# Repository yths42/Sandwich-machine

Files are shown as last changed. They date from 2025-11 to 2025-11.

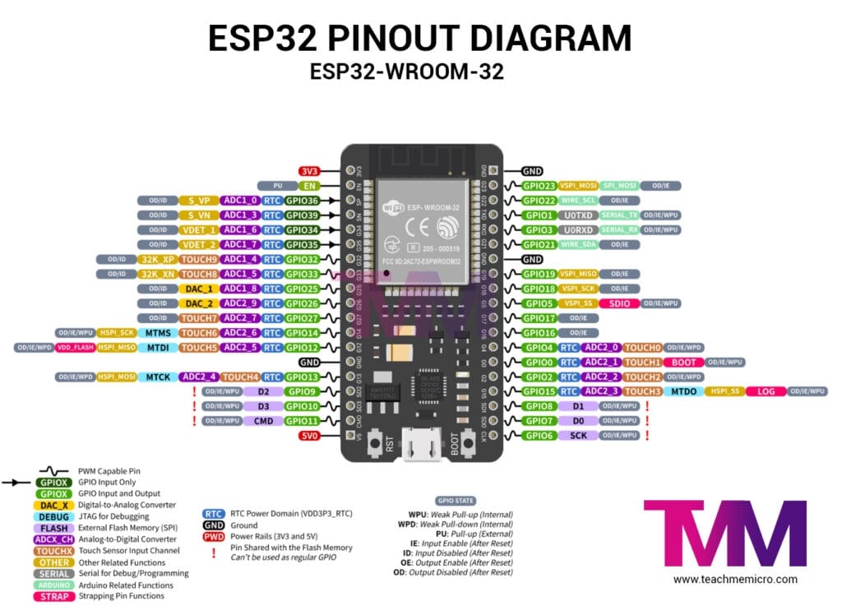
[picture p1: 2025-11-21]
ESP32 Pinout Diagram.jpg

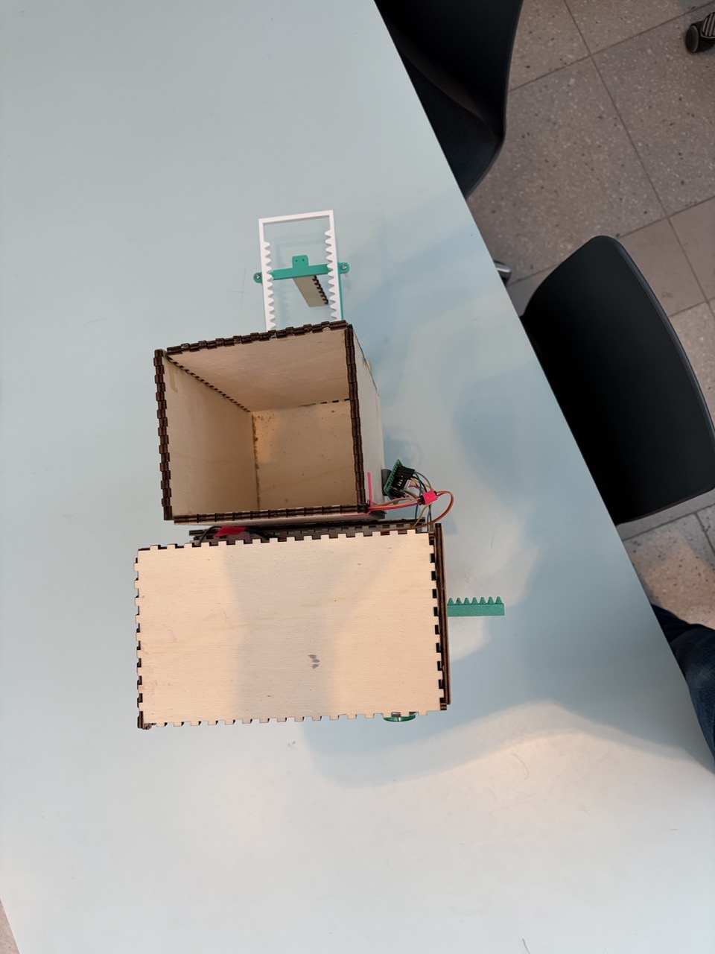
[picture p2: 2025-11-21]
Pictures of machine/IMG_8091 Large.jpeg

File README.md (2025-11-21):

# Sandwich-machine
A machine that makes a jam sandwich with the press of a button. - the best thing since sliced bread.
All further documentation in norwegian

Virkemåte:
Maskinen starter ved at man plasserer en tallerken under luken og trykker på startknappen.
Dette aktiverer en motor som roterer et tannhjul som igjen dytter en plate som dytter en
brødskive fra stabelen til posisjon på en motorisert luke under syltetøyet.

Deretter vil en motor vri et tannhjul som dytter en pinne som klemmer en pose med syltetøy, posen med syltetøy har en åpning under som syltetøyet kan komme ut av. Den høye viskositeten til syltetøyet vil sørge for at syltetøyet ikke renner ut av seg selv.

En luke åpnes deretter under brødskiven som er styrt av to servomotorer. De er skal vri
lukedørene 90 grader, vente i 0.5 sekunder og så vris tilbake. Dette gjør at brødskiven lander
på tallerkenen.

Nå startes dytteren på nytt slik at en til brødskive dyttes på luken, og luken åpnes, slik at
brødskiven detter oppå den opprinnelige brødskiven.

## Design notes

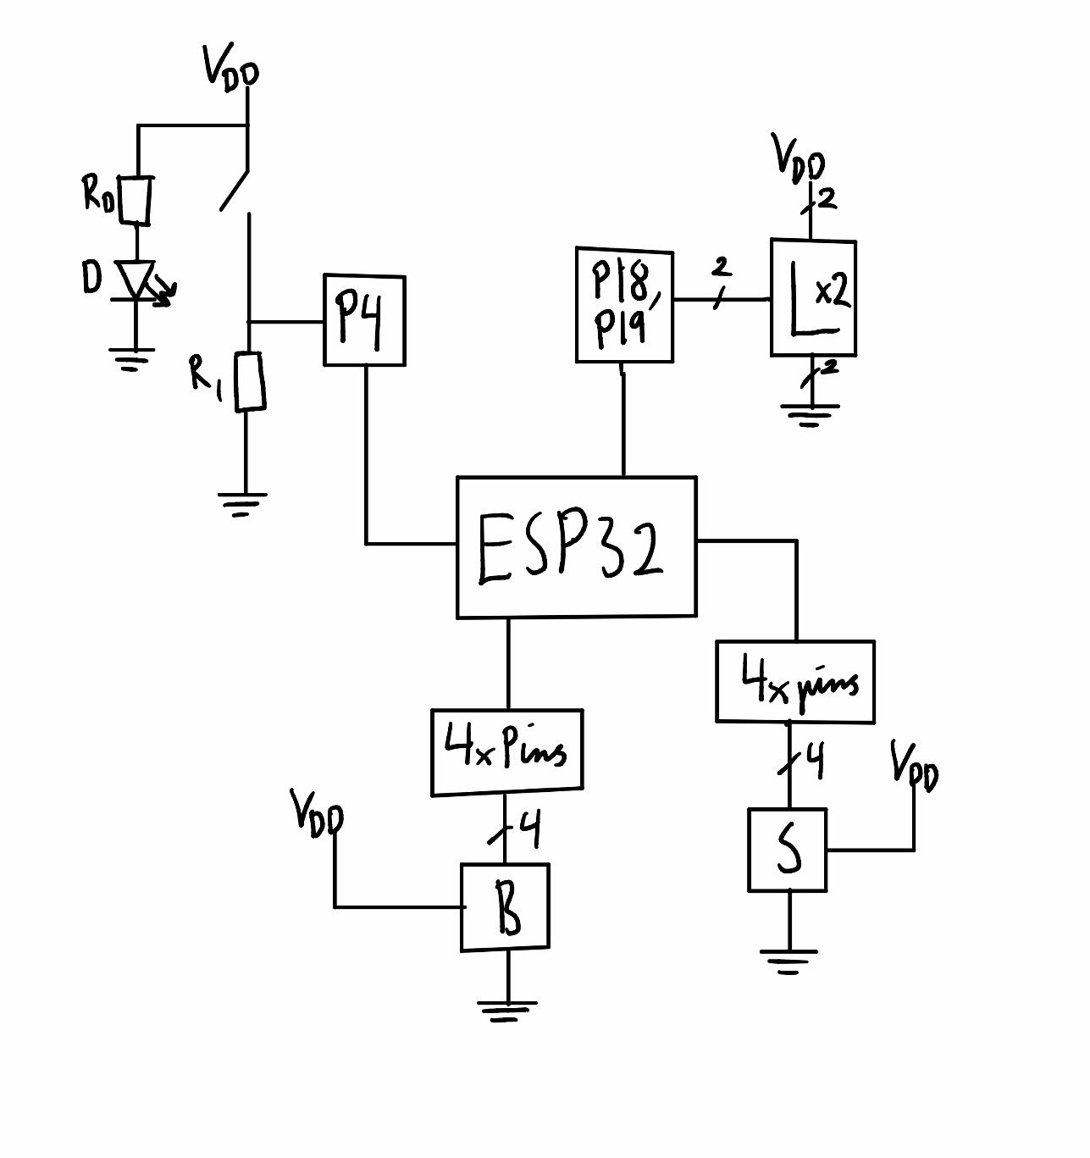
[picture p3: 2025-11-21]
Fullstendig_krets.jpg

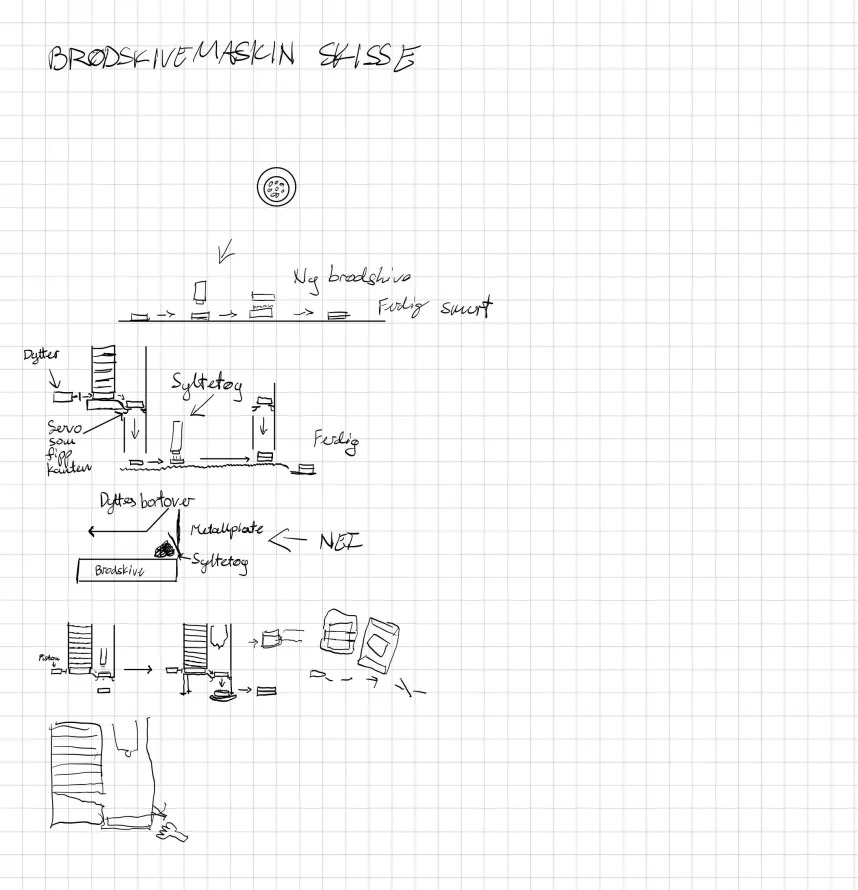
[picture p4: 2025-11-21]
Brødskivemaskin skisse.jpg

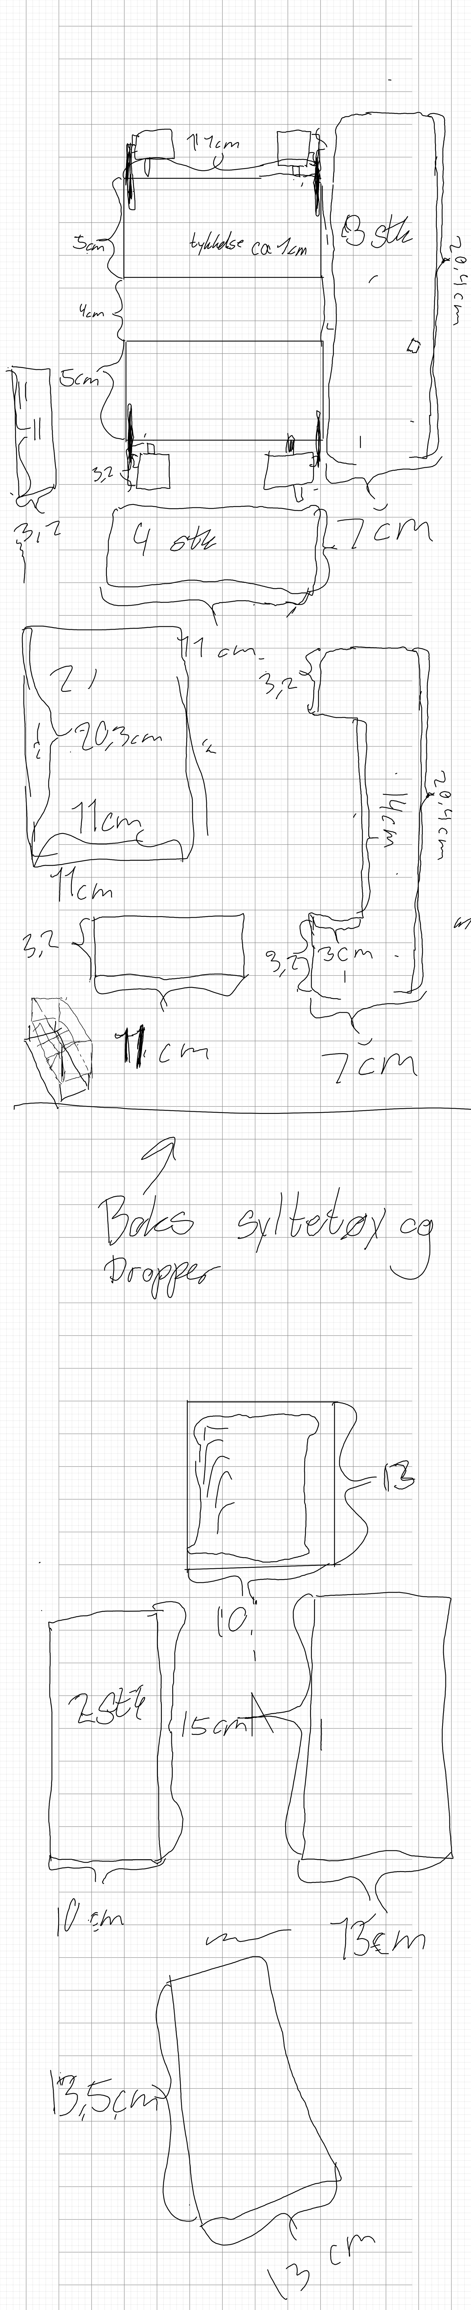
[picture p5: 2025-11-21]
Mål for boks/Elsysprosjekt 1 - page 1.png

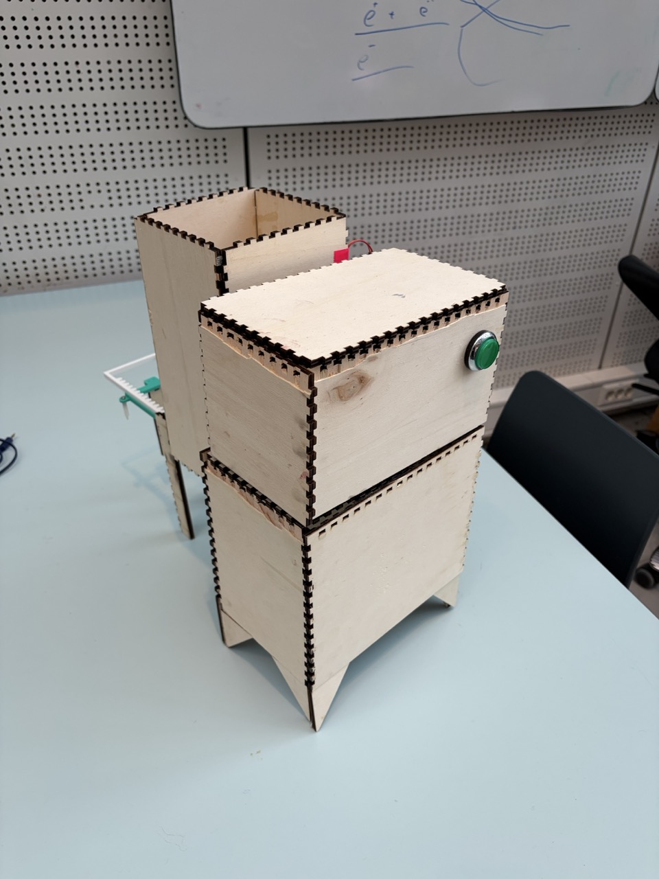
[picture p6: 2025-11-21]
Pictures of machine/IMG_8089 Large.jpeg

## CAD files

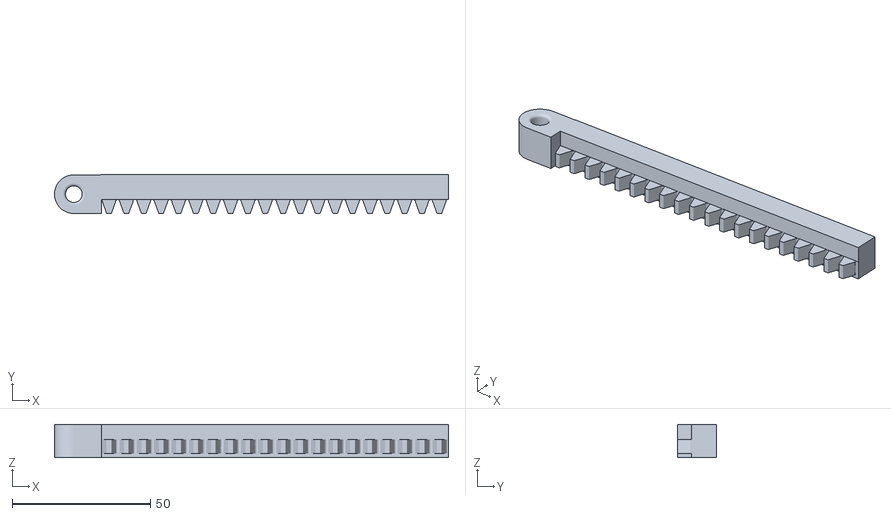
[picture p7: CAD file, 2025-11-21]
Syltetøy skviser/RackWHole01.stl
142.6 x 14.1 x 12.0

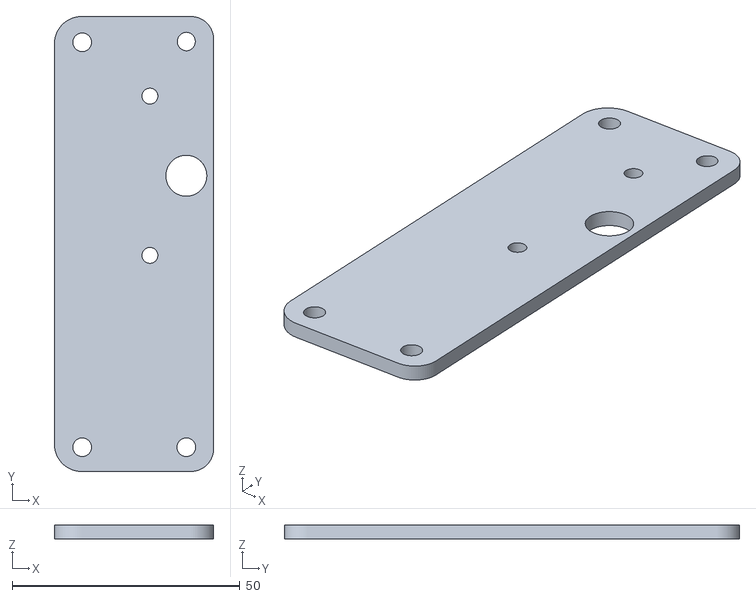
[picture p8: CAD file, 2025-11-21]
Brød dytter/motorplate.stl
35.0 x 100.0 x 3.00

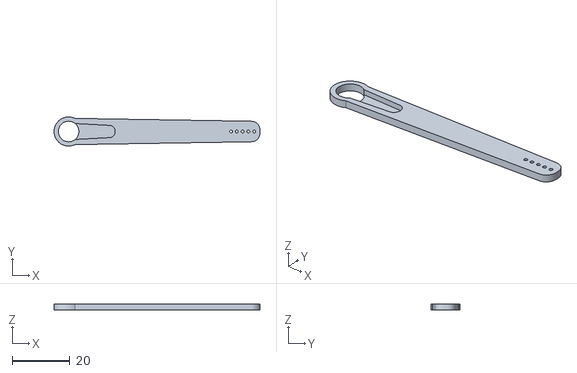
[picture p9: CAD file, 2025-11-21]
Utvidelse for servo motorer/extender_50mm.STL
71.1 x 10.1 x 2.00

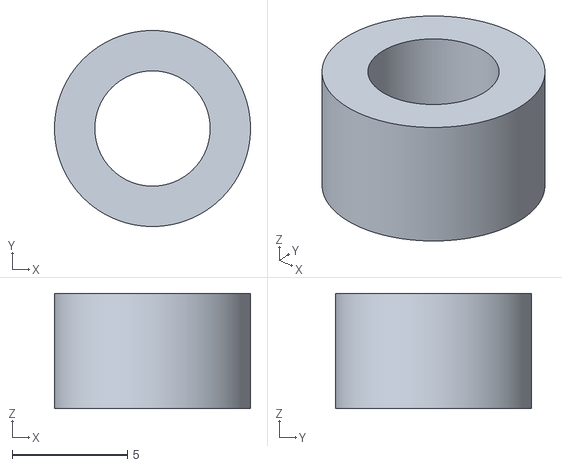
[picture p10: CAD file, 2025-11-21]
Brød dytter/spacer.stl
8.50 x 8.50 x 5.00

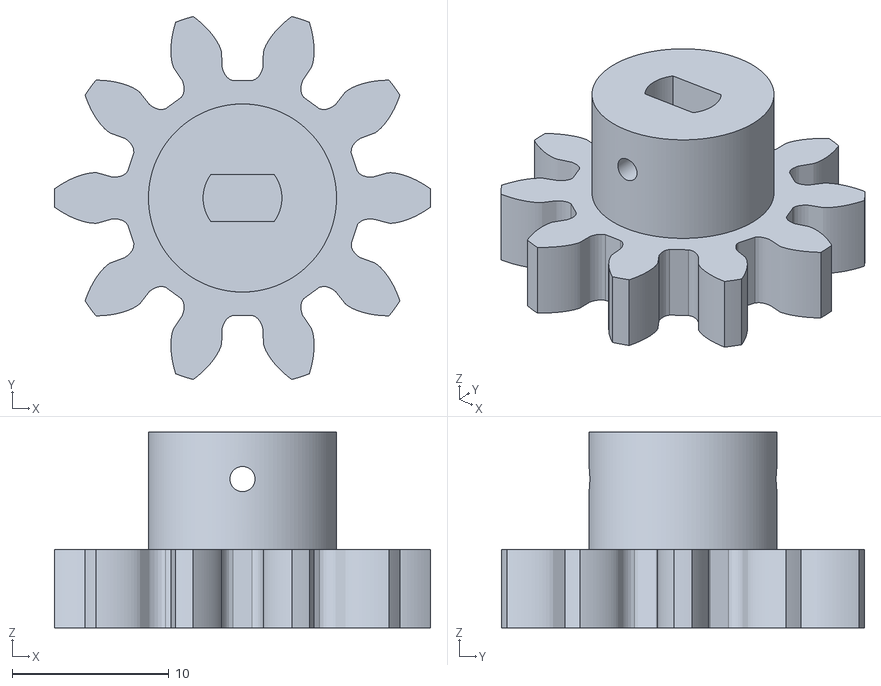
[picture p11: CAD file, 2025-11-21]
Syltetøy skviser/ActuatorGear01.stl
24.0 x 23.2 x 12.5

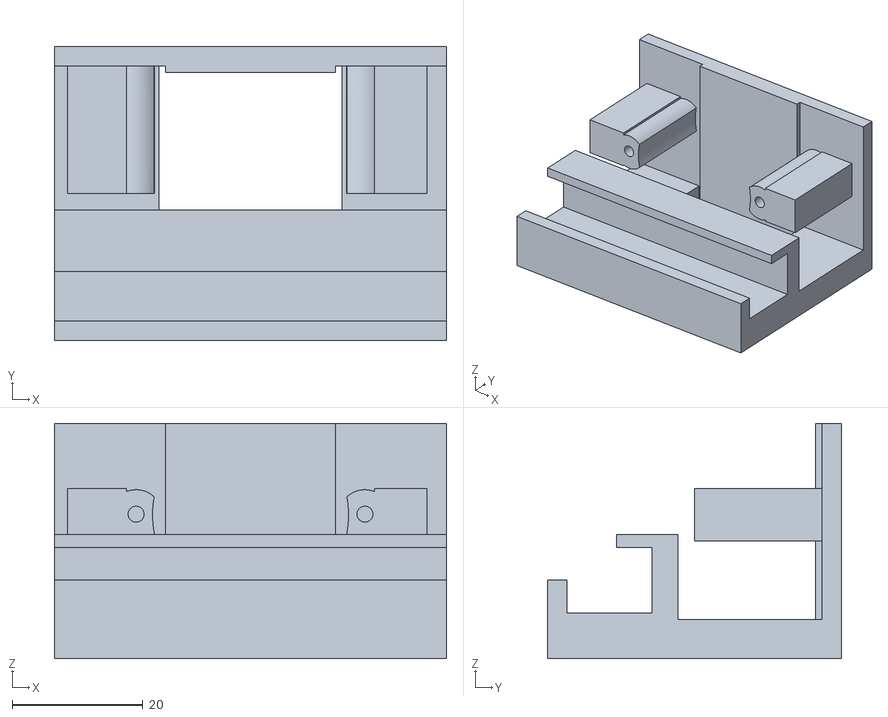
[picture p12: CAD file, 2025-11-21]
Syltetøy skviser/ActuatorMotorSupport01.stl
60.0 x 45.0 x 36.0

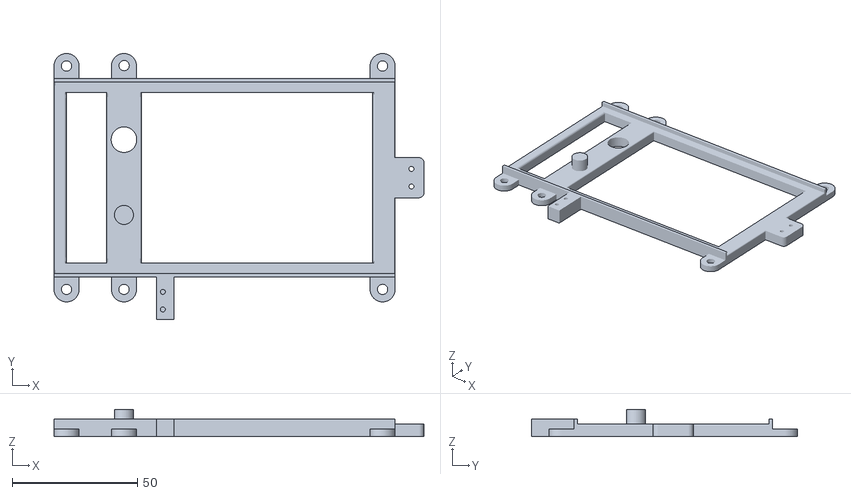
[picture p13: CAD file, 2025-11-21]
Brød dytter/base.stl
147.4 x 106.0 x 10.9

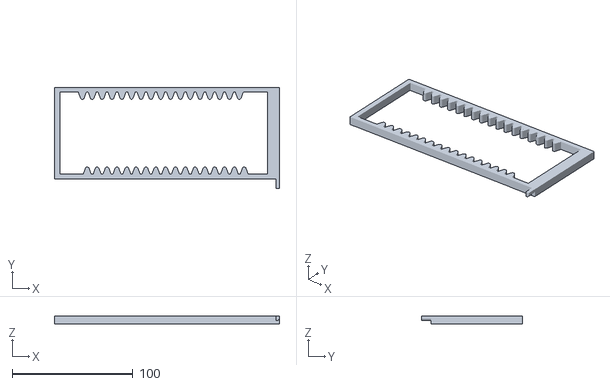
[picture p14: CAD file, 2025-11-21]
Brød dytter/Piniongear_extended.stl
186.5 x 84.0 x 7.00

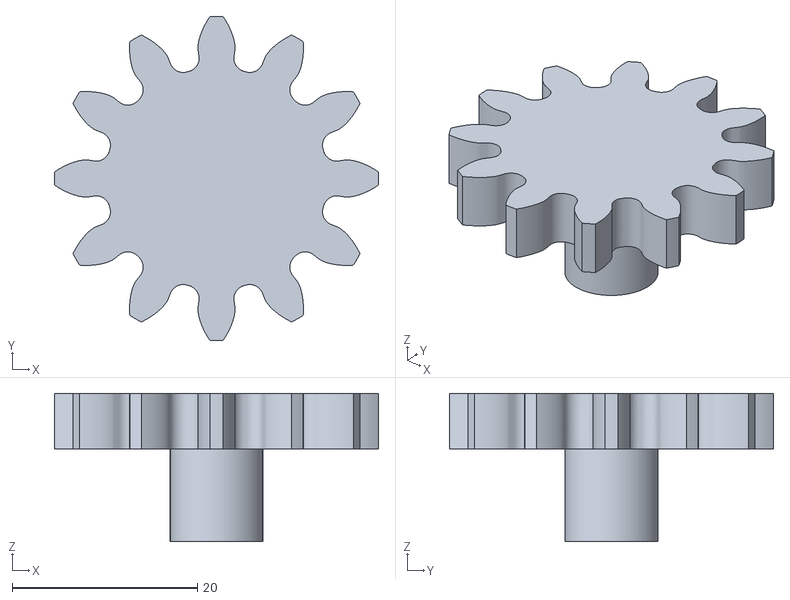
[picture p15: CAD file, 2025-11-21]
Brød dytter/gear2.stl
35.0 x 35.0 x 16.0

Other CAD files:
Brød dytter/gear1.stl

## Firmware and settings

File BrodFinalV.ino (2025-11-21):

#include <ESP32Servo.h>
#include <Stepper.h>

const int stepsPerRevolution = 2048;  // 28BYJ-48
const int stepsMotorSkalGa = 2992;    // 34*88

// --- Servoer ---
Servo myServo1;
Servo myServo2;
const int servoPin1 = 18;
const int servoPin2 = 19;

// --- Knapp (til GND, intern pull-up) ---
const int buttonPin = 4;

// --- Stepper pinner (ULN2003) ---
// pins brød dytter
#define IN1 21
#define IN2 22
#define IN3 23
#define IN4 25

// pins syltetøy
#define IN5 26
#define IN6 27
#define IN7 32
#define IN8 33

Stepper brodDytter(stepsPerRevolution, IN1, IN3, IN2, IN4);
Stepper syltetoyKlemmer(stepsPerRevolution, IN5, IN7, IN6, IN8);

int buttonState;
int lastButtonState;  // forrige knapp-status

// --- Hjelpefunksjoner ---

// Jiggle når BARE brød dytter skal gå fremover.
// Nettoposisjon etterpå = totalSteps (f.eks. 2640).
void brodDyttJiggleAlene(int totalSteps) {
  long twoThirds = (totalSteps * 2) / 3;     // ~2/3 frem
  long oneQuarter = totalSteps / 4;          // 1/4 tilbake
  long finalFwd = totalSteps - (twoThirds - oneQuarter); // resten til full frem

  // frem ~2/3
  brodDytter.step((int)twoThirds);
  // tilbake 1/4
  brodDytter.step(-(int)oneQuarter);
  // frem til full
  brodDytter.step((int)finalFwd);
}

// Jiggle når brød dytter går fremover SAMTIDIG som syltetøy går tilbake.
// Holder jevn bevegelse ved å kjøre i små "chunks".
void brodDyttJiggleMedSyltetoy(int totalSteps, int chunkBread = 10, int chunkJam = 5, int delayMs = 15) {
  // chunkJam/chunkBread = 0.5, matcher ca. den tidligere 15 pr 30
  long twoThirds = (totalSteps * 2) / 3;     
  long oneQuarter = totalSteps / 4;          
  long finalFwd = totalSteps - (twoThirds - oneQuarter);

  auto stepSegment = [&](long segSteps, int breadDir) {
    long remaining = segSteps;
    int jamDir = +1; // syltetøy går tilbake (samme retning som før: positivt talte steg)
    // kjør i "chunks" for jevn bevegelse
    while (remaining > 0) {
      int stepNow = (remaining >= chunkBread) ? chunkBread : (int)remaining;
      // brød
      brodDytter.step(breadDir * stepNow);
      // syltetøy (holder 1/2 forhold)
      int jamStepsNow = (stepNow * chunkJam) / chunkBread; // skal bli 5 når stepNow=10
      if (jamStepsNow == 0 && stepNow > 0) jamStepsNow = 1; // sikrer litt bevegelse
      syltetoyKlemmer.step(jamDir * jamStepsNow);
      delay(delayMs);
      remaining -= stepNow;
    }
  };

  // frem ~2/3
  stepSegment(twoThirds, +1);
  // tilbake 1/4 (brød litt tilbake, syltetøy fortsetter tilbake)
  stepSegment(oneQuarter, -1);
  // frem til full
  stepSegment(finalFwd, +1);
}

void setup() {
  Serial.begin(115200);

  // Servoer til luken
  myServo1.attach(servoPin1);
  myServo2.attach(servoPin2);

  // Knapp (intern pullup = HIGH når ikke trykket)
  pinMode(buttonPin, INPUT_PULLUP);

  buttonState = digitalRead(buttonPin);
  lastButtonState = buttonState;
  Serial.print("Start knapp-state: ");
  Serial.println(buttonState);

  // Stepper-hastighet (RPM)
  brodDytter.setSpeed(10);
  syltetoyKlemmer.setSpeed(7);

  Serial.println("Init OK");
}

void loop() {
  // Les knapp
  lastButtonState = buttonState;
  buttonState = digitalRead(buttonPin);

  // Sjekker om knappen nettopp BLE trykket (HIGH -> LOW)
  if (lastButtonState == HIGH && buttonState == LOW) {
    Serial.println("Knapp trykket, starter sekvens");

    // --- 1) Brød dyttes frem med jiggle (alene) til nett +2640 ---
    brodDyttJiggleAlene(stepsMotorSkalGa);

    // --- 2) Syltetøy klemmes, samtidig som brød dytter går tilbake (vanlig tilbake) ---
    for (int angle = 88; angle > 0; angle--) {
      syltetoyKlemmer.step(-15);
      brodDytter.step(-34);
      delay(15);
    }

    // --- 3) Luke åpnes ---
    for (int angle = 0; angle < 88; angle++) {
      myServo1.write(angle);
      myServo2.write(angle);
      delay(10);
    }

    delay(500);

    // --- 4) Luke lukkes ---
    for (int angle = 88; angle > 0; angle--) {
      myServo1.write(angle);
      myServo2.write(angle);
      delay(10);
    }

    // --- 5) Nytt brød dyttes frem med jiggle, mens syltetøy går tilbake jevnt ---
    syltetoyKlemmer.setSpeed(10);
    brodDyttJiggleMedSyltetoy(stepsMotorSkalGa, /*chunkBread=*/10, /*chunkJam=*/10, /*delayMs=*/20);

    delay(500);

    // --- 6) Luke åpnes igjen ---
    for (int angle = 0; angle < 88; angle++) {
      myServo1.write(angle);
      myServo2.write(angle);
      delay(15);
    }

    // --- 7) Luke lukkes, brød dytter går vanlig tilbake ---
    for (int angle = 88; angle > 0; angle--) {
      myServo1.write(angle);
      myServo2.write(angle);
      brodDytter.step(-34);
      delay(15);
    }

    // Vent til knappen SLIPPES før vi godtar nytt trykk
    while (digitalRead(buttonPin) == LOW) {
      delay(10);
    }
    delay(50);
  }
}
